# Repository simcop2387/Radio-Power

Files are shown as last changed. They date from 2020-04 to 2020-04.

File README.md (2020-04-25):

My new car radio draws too much standby power and eventually drains the car battery when sitting for a week or two.  This is a quick board to fix it.

It uses a P-Channel MOSFET to switch the power to the radio, so that it's only got power when the ACC power line is live, or the micro-controller (attiny85) keeps power going.

The attiny85 monitors the battery voltage and turns off the P-Channel MOSFET when the battery voltage drops below 11.75V (subject to be changed), or about 4 days has passed.

Once the P-Channel MOSFET has been turned off, it won't turn on again until the ACC line becomes live again.  This will only happen when starting the car.

Schematic
Board

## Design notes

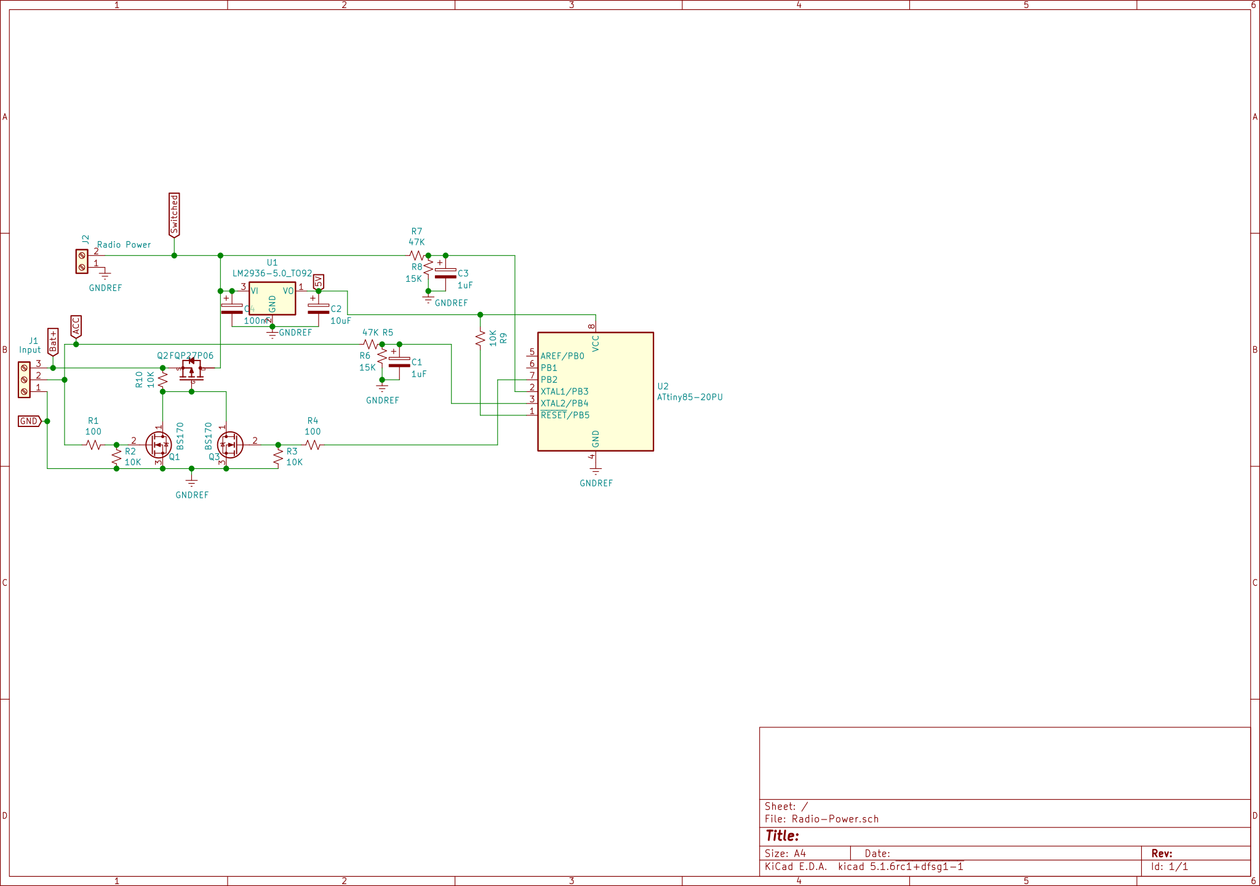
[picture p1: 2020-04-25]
Radio-Power.png

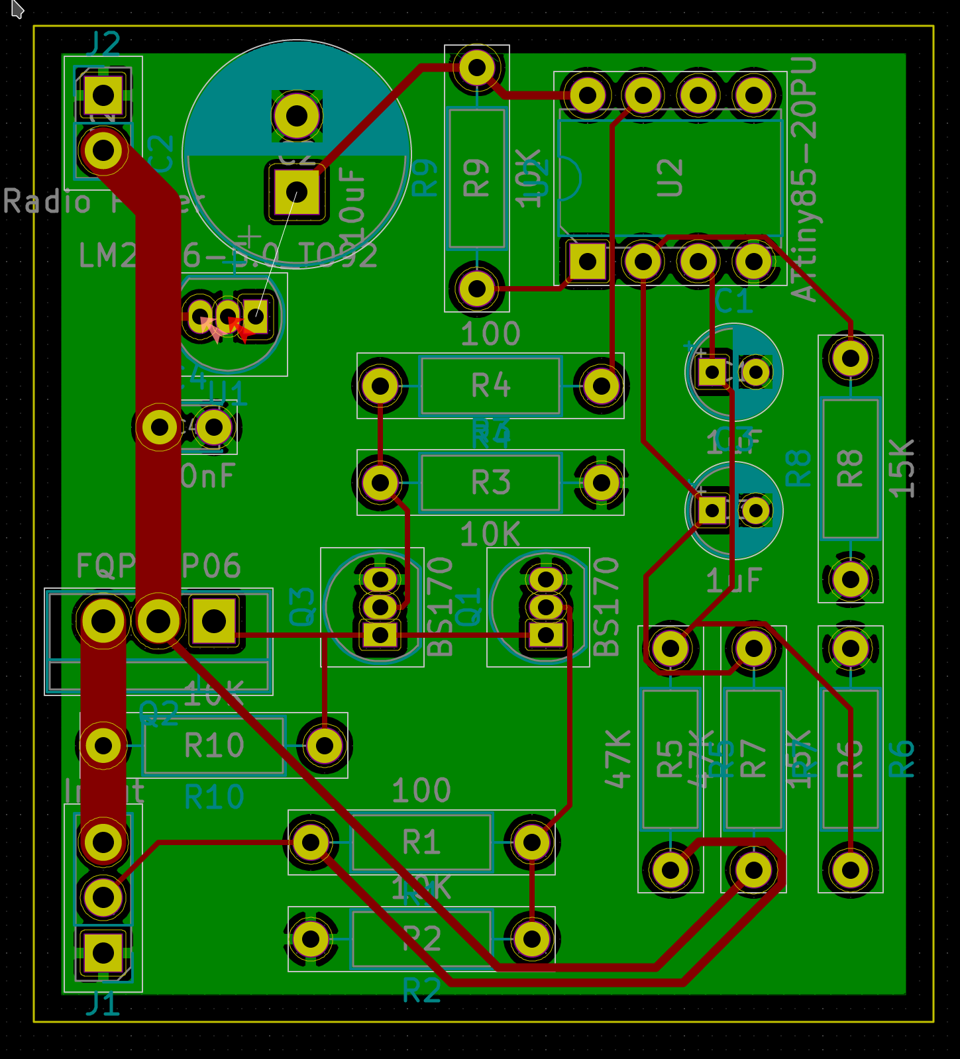
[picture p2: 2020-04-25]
board.png

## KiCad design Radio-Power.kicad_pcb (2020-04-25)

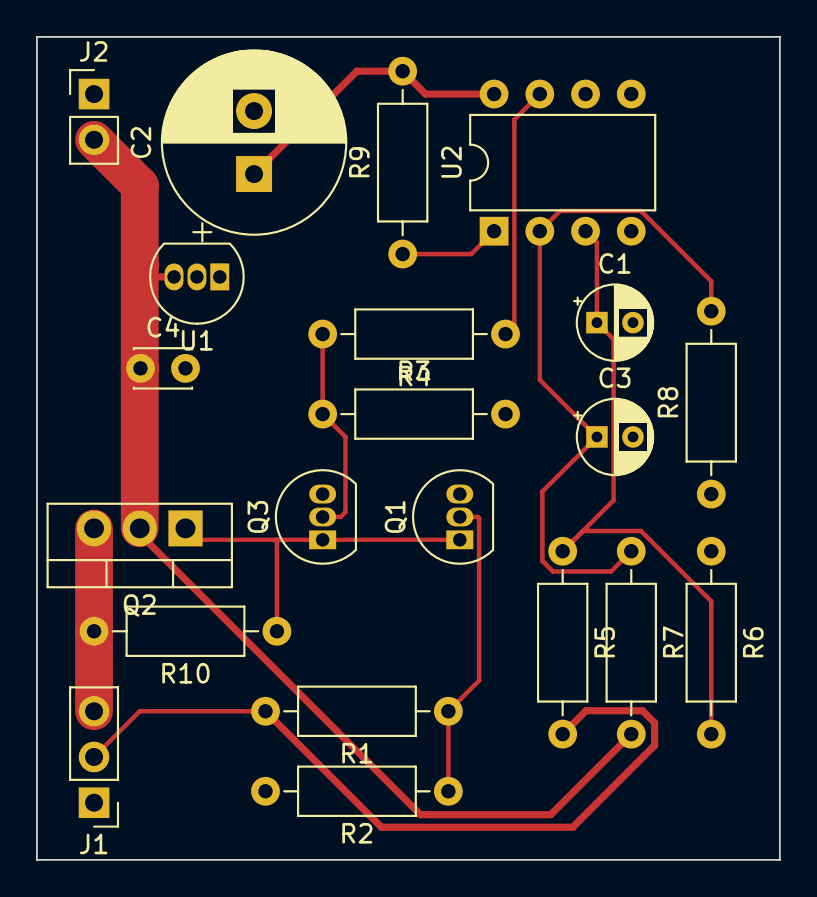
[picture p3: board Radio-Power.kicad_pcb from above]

Board: 2 copper layers, 41.3 x 45.7 mm, 21 parts (0 on the bottom side), 12 nets.

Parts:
C1, C3: 1uF; CP_Radial_D4.0mm_P2.00mm
C2: 10uF; CP_Radial_D10.0mm_P3.50mm
C4: 100nF; C_Disc_D3.0mm_W2.0mm_P2.50mm
J1: Input; PinHeader_1x03_P2.54mm_Vertical
J2: Radio Power; PinHeader_1x02_P2.54mm_Vertical
Q1, Q3: BS170; TO-92_Inline
Q2: FQP27P06; TO-220-3_Vertical
R1, R4: 100; R_Axial_DIN0207_L6.3mm_D2.5mm_P10.16mm_Horizontal
R2, R3, R9, R10: 10K; R_Axial_DIN0207_L6.3mm_D2.5mm_P10.16mm_Horizontal
R5, R7: 47K; R_Axial_DIN0207_L6.3mm_D2.5mm_P10.16mm_Horizontal
R6, R8: 15K; R_Axial_DIN0207_L6.3mm_D2.5mm_P10.16mm_Horizontal
U1: LM2936-5.0_TO92; TO-92_Inline
U2: ATtiny85-20PU; DIP-8_W7.62mm

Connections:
5V: C2.1, R9.2, U1.1, U2.8
ACC: J1.2, R1.2, R5.2
Bat+: J1.3, Q2.3, R10.2
GND: C1.2, C2.2, C3.2, C4.2, J1.1, J2.1, Q1.3, Q3.3, R2.2, R3.2, R6.1, R8.1, U1.2, U2.4
unnamed: C1.1, R5.1, R6.2, U2.3
unnamed: C3.1, R7.1, R8.2, U2.2
unnamed: Q1.1, Q2.1, Q3.1, R10.1
unnamed: Q1.2, R1.1, R2.1
unnamed: Q3.2, R3.1, R4.2
unnamed: R4.1, U2.7
unnamed: R9.1, U2.1
Switched: C4.1, J2.2, Q2.2, R7.2, U1.3

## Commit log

2020-04-24 Mostly ready, need proper footprint for in/out terminal blocks
    [Radio-Power.kicad_pcb, Radio-Power.sch]
2020-04-24 Try to add schematic to page
2020-04-24 Forgot a resistor
    [Radio-Power.kicad_pcb, Radio-Power.sch]
2020-04-24 Fix rendered schematic
    [Radio-Power.sch]
2020-04-24 Gerbers and some minor changes
    [Radio-Power-B_Cu.gbr, Radio-Power-B_Mask.gbr, Radio-Power-B_Paste.gbr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]
2020-04-25 Change some things, use switched power for measurement to prevent accidental power flow into the uC
    [Radio-Power.kicad_pcb, Radio-Power.sch]
2020-04-25 Replot everything
    [Radio-Power-B_Cu.gbr, Radio-Power-B_Mask.gbr, Radio-Power-B_Paste.gbr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]
2020-04-25 Board updated, switched to lm2936 for 5v regulator
    [Radio-Power-B_Cu.gbr, Radio-Power-B_Mask.gbr, Radio-Power-B_Paste.gbr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]
2020-04-25 Update readme to include board look
2020-04-25 Minor updates, add a cap and move the regulator
    [Radio-Power-B_Cu.gbr, Radio-Power-B_Mask.gbr, Radio-Power-B_Paste.gbr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]
